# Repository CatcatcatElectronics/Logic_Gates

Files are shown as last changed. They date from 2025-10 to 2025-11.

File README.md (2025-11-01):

# Logic_Gates
A game, a simulator, a gift - the development of logical thinking. The Logic Gate project is designed to develop logical thinking in children and can also be used as a kit - a board for learning C programming and working with microcontrollers from Microchip Corporation.

**_Printed circuit board design_**

## Task:

> Build a simple PCB tutorial project, control LEDs with built-in drivers, explore capacitive sensors for user interface, and learn how to work with a UART serial interface (for DIY projects).

## System Parameters:
> **MCU** - PIC18F27Q84-I/SS,
> **LED_CHIP** - SK6812MINI-EA,
> **USB-BRIDGE** - CH343P,
> **Connecting to a PC** - TYPE-C.

## Functional Diagram project
---

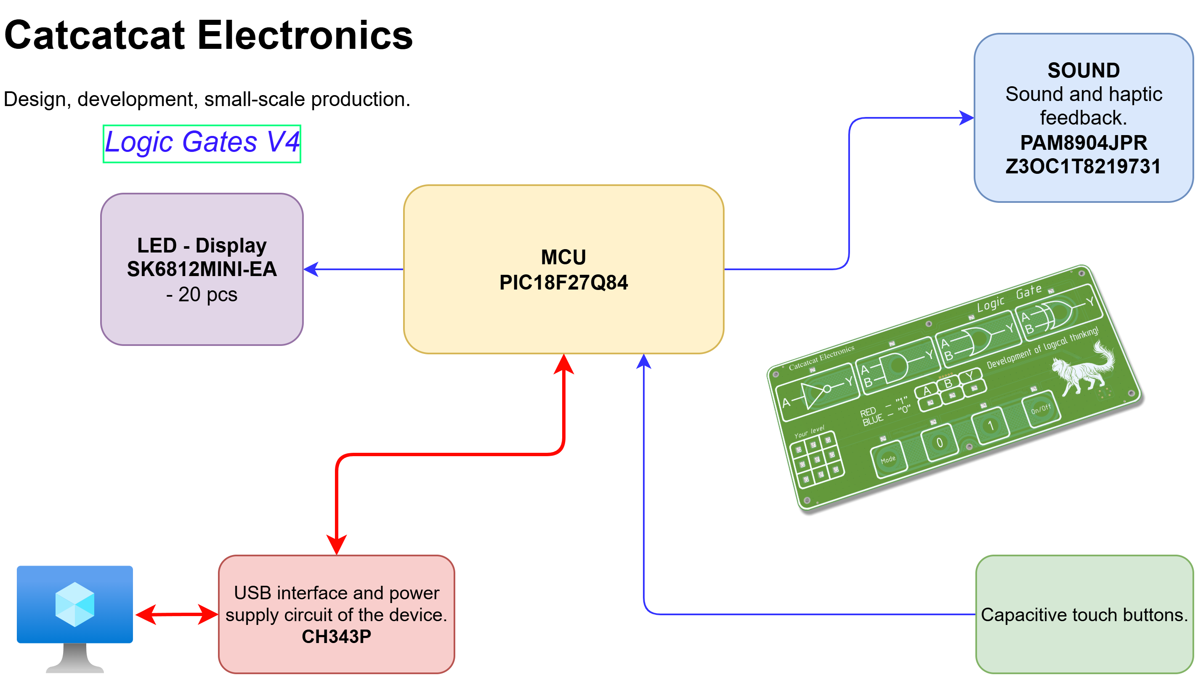
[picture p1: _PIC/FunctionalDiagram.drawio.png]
Functional Diagram of image Functional Diagram


---

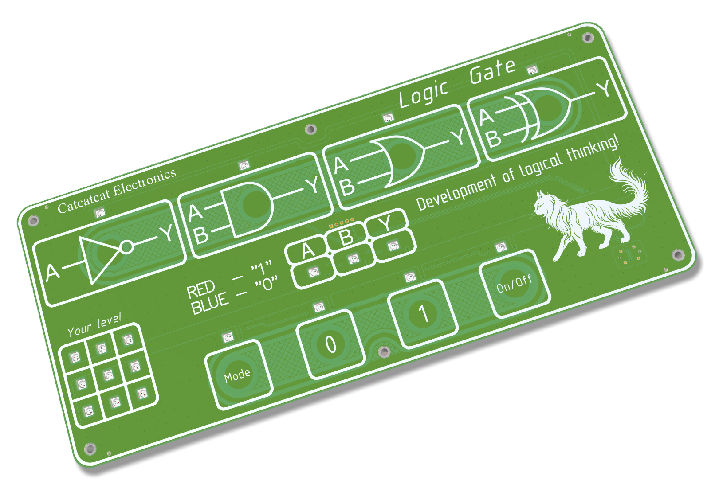
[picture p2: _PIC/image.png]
Semantic description of image Task


## Schematic

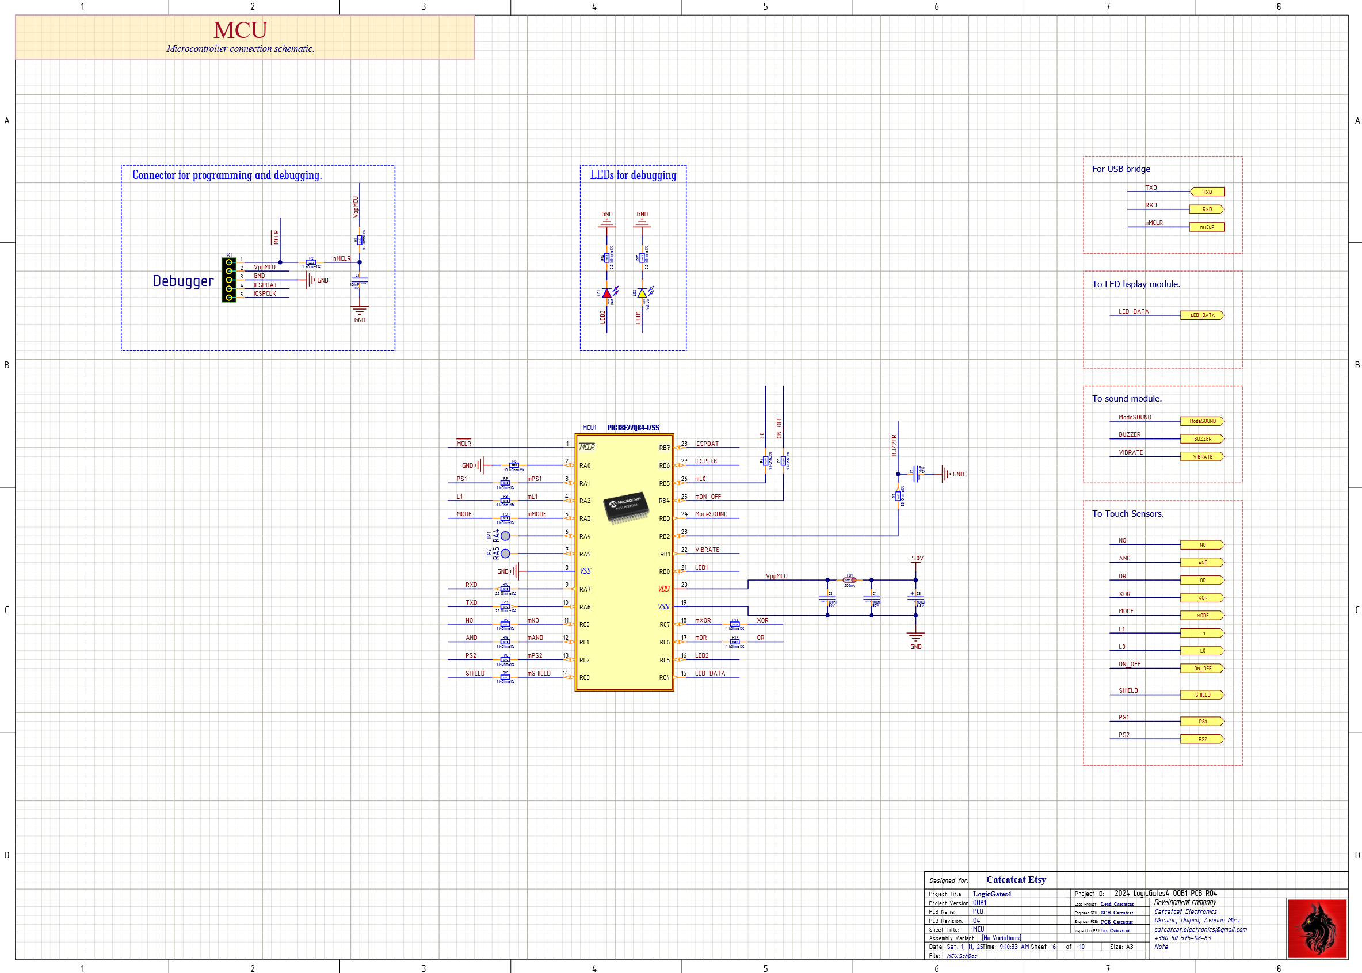
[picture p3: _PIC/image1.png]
Semantic description of image MCU


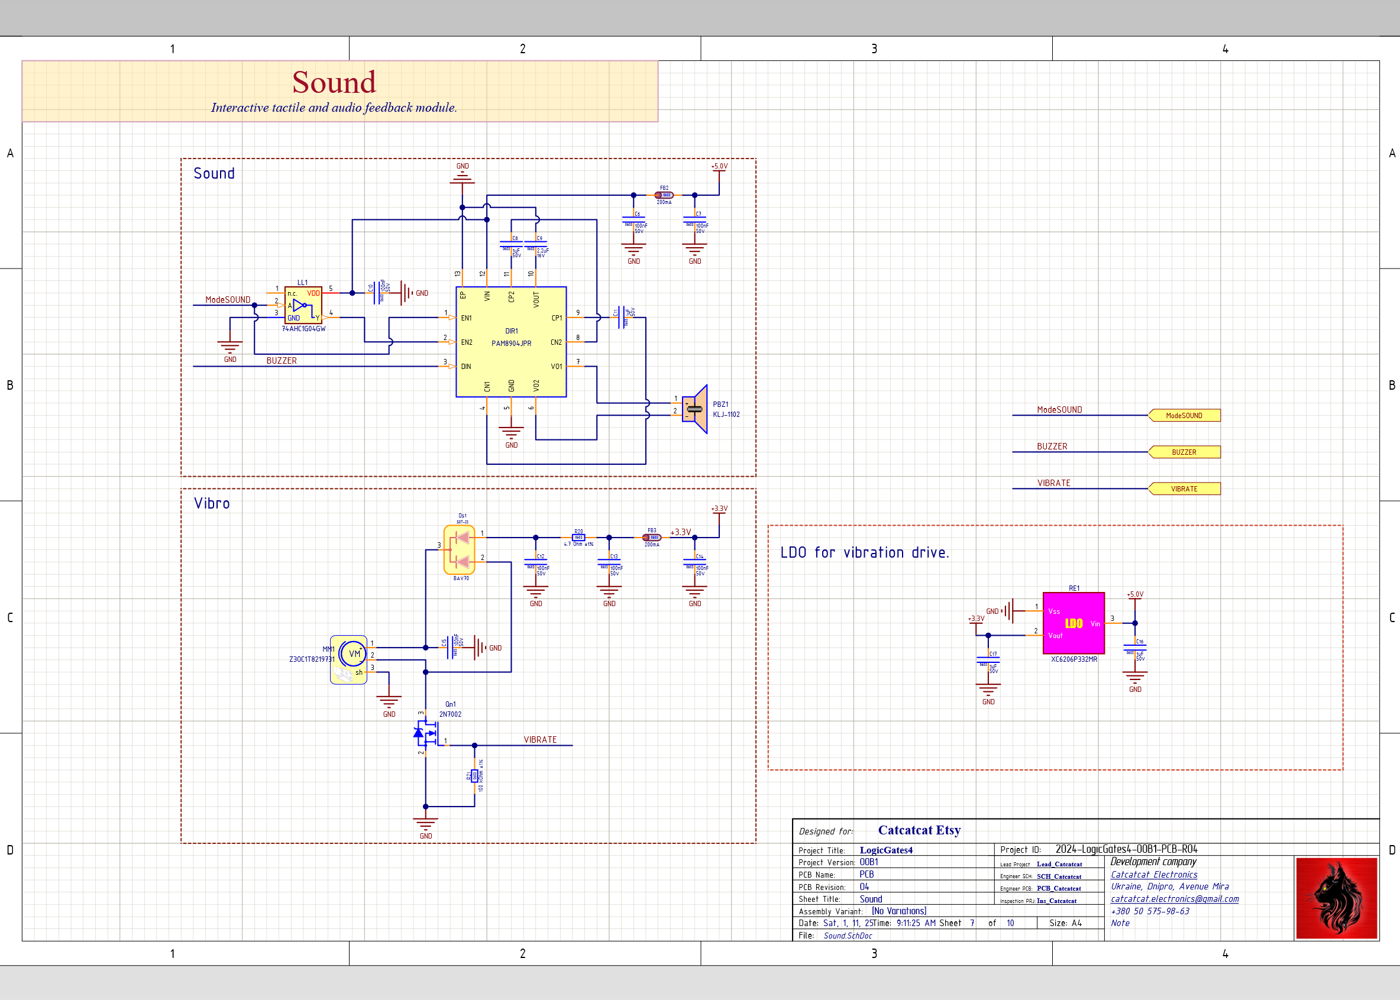
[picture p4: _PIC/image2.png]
Semantic description of image SOUND


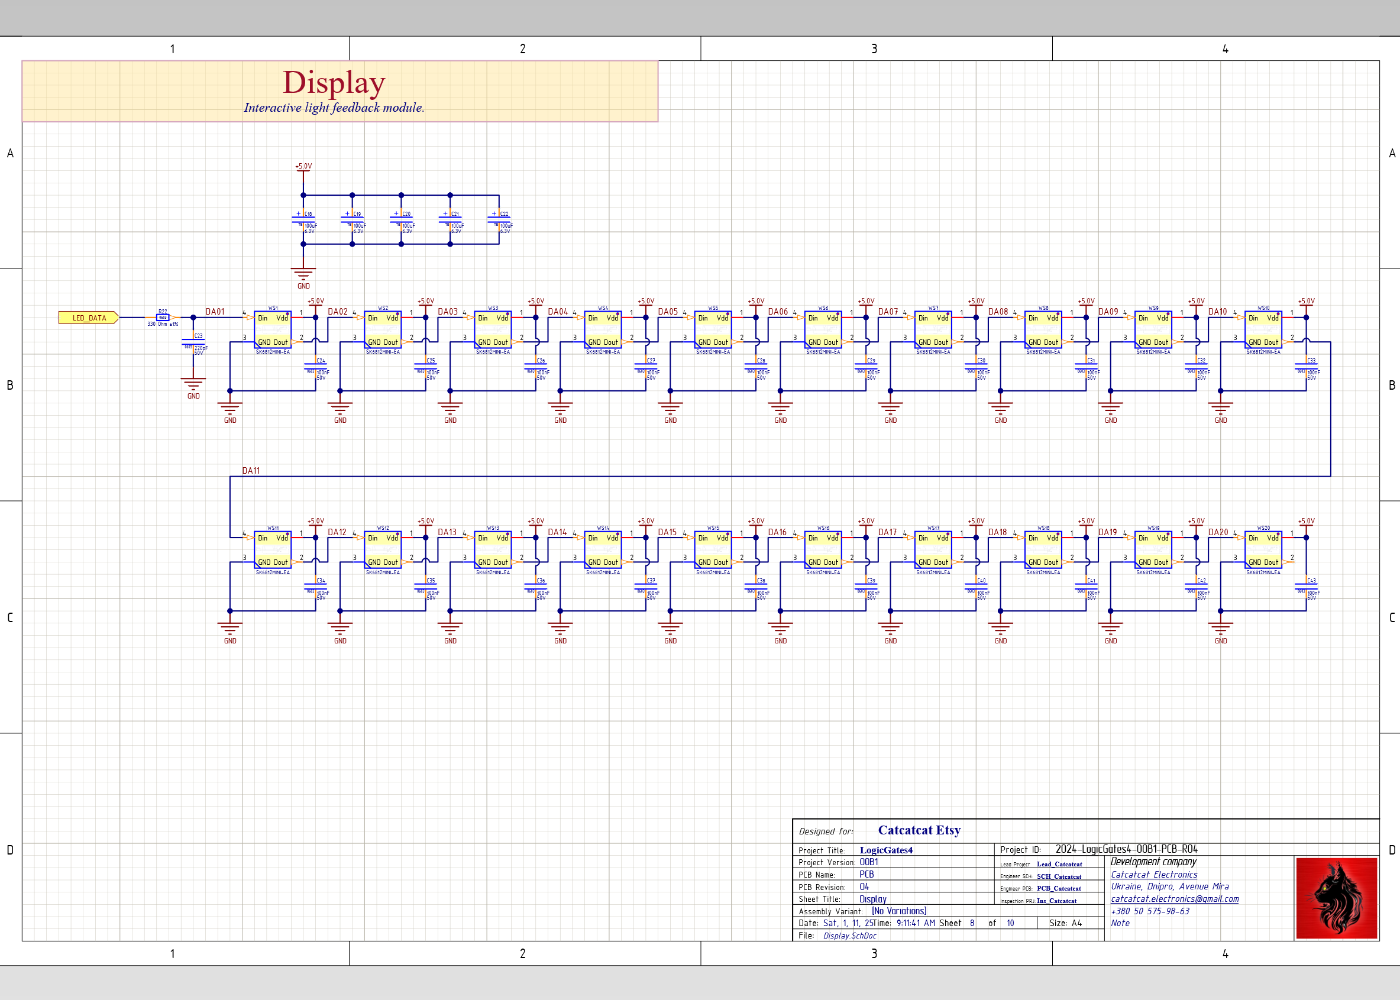
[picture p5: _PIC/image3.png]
Semantic description of image LED-DISPLAY


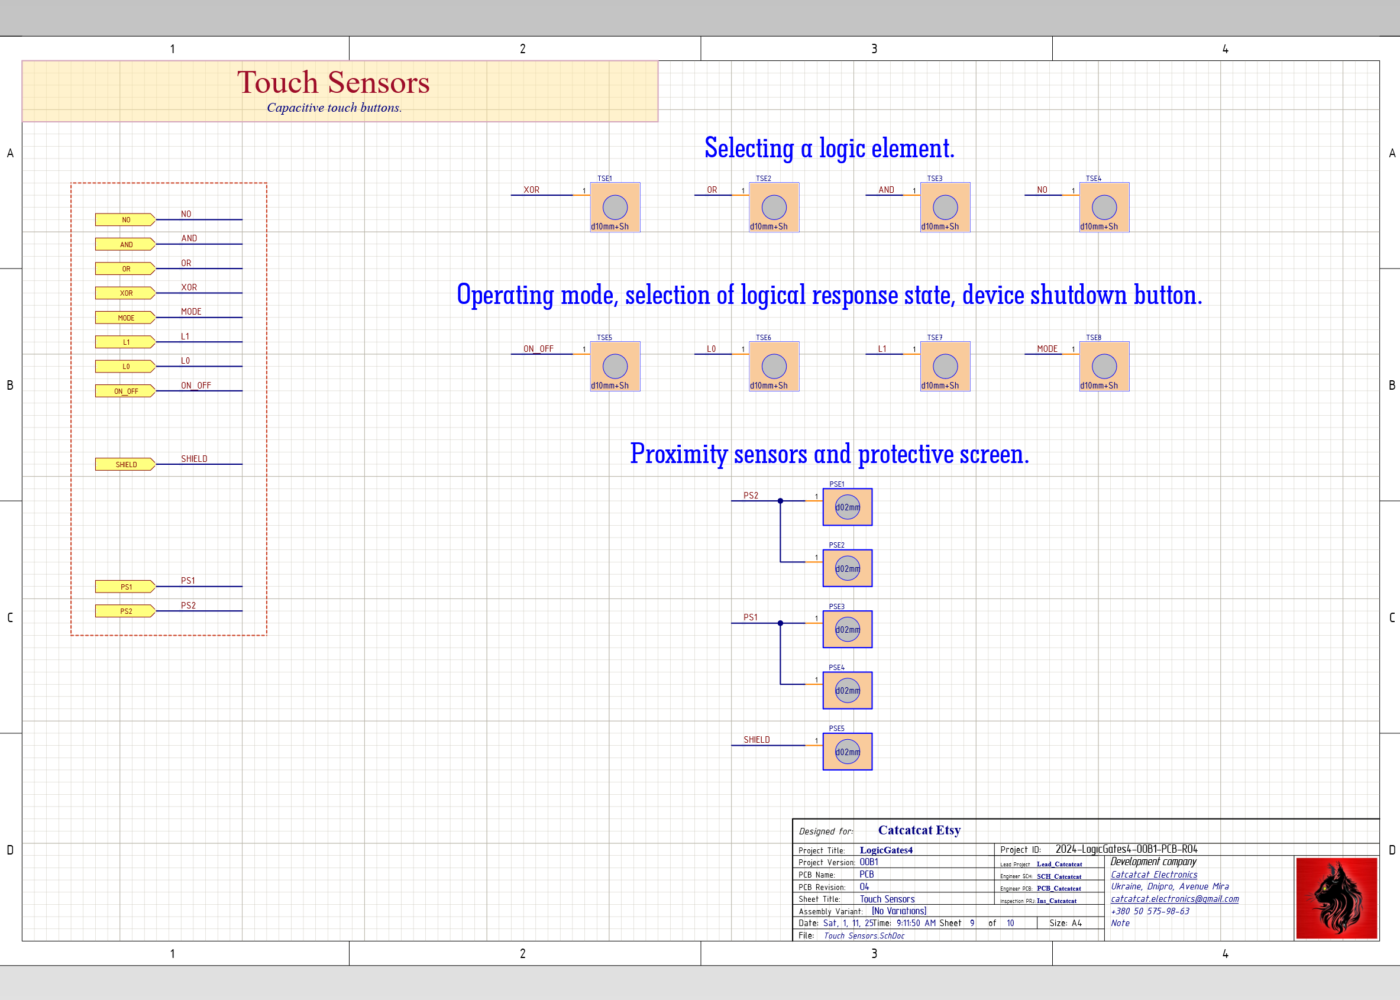
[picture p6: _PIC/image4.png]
Semantic description of image TOUCH


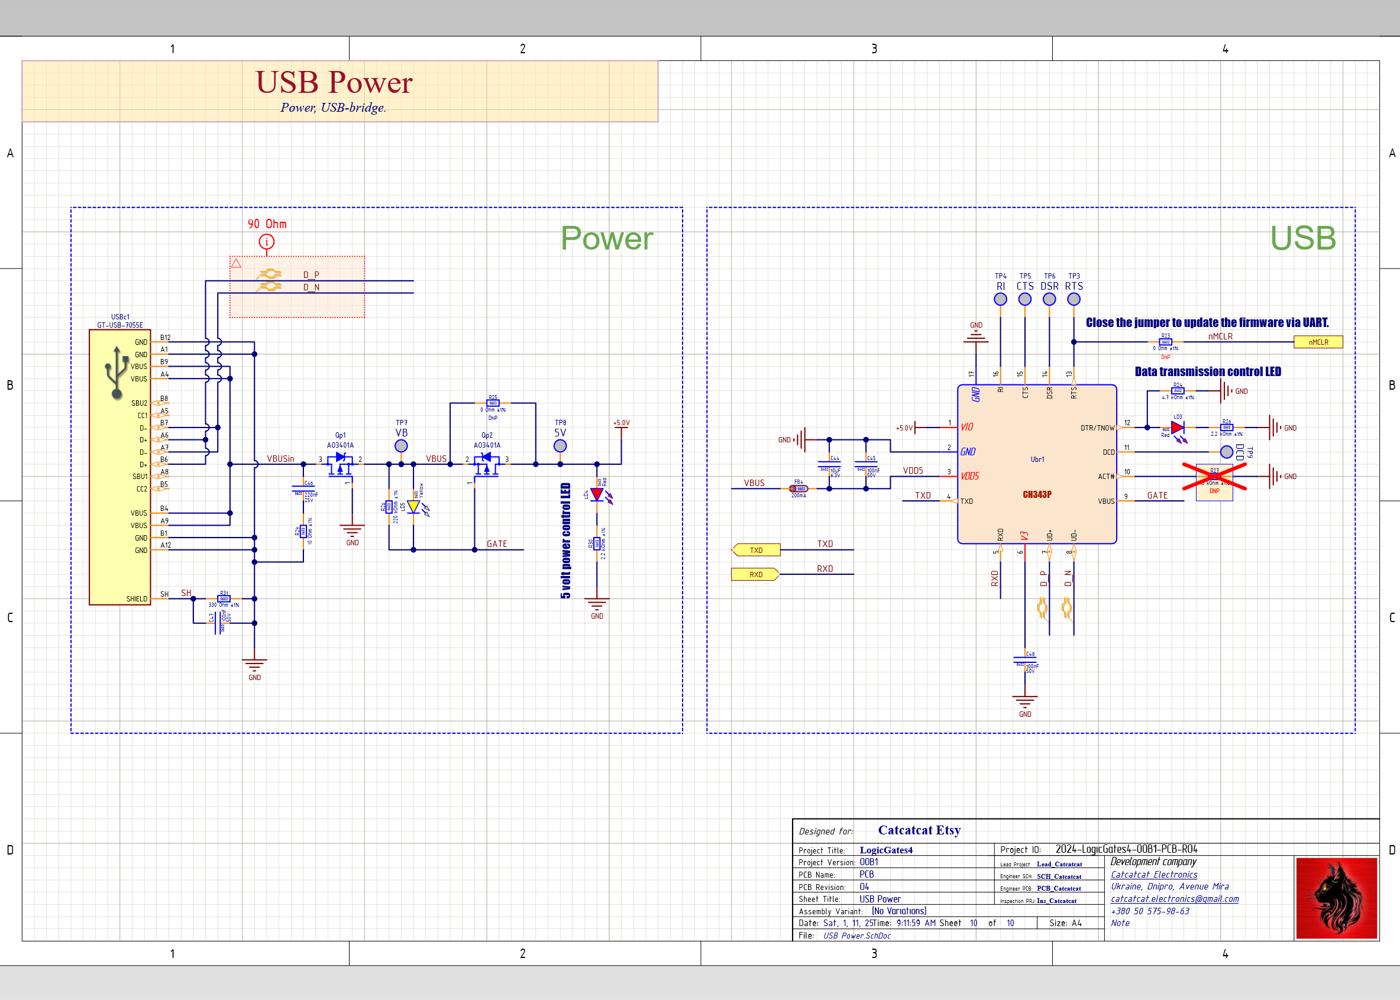
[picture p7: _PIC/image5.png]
Semantic description of image USB-POWER


[**_Schematic_**](https://github.com/CatcatcatElectronics/Logic_Gates/blob/main/Logic_Gates_4/Project%20Outputs/Production%20Files%20JLCPCB/Schematic/2024-LogicGates4-00B1-PCB-R04-Sch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 "View")

[**_Open catalog_**](https://github.com/CatcatcatElectronics/Logic_Gates/tree/main/Logic_Gates_4/Project%20Outputs/Production%20Files%20JLCPCB/Schematic "Open")

---

## 3D Models (STEP & Parasolid)

[**_Open catalog_**](https://github.com/CatcatcatElectronics/Logic_Gates/blob/main/Logic_Gates_4/Project%20Outputs/Production%20Files/3D%20model%20PCB/PCB.rar "Open")

---

## Draftsman
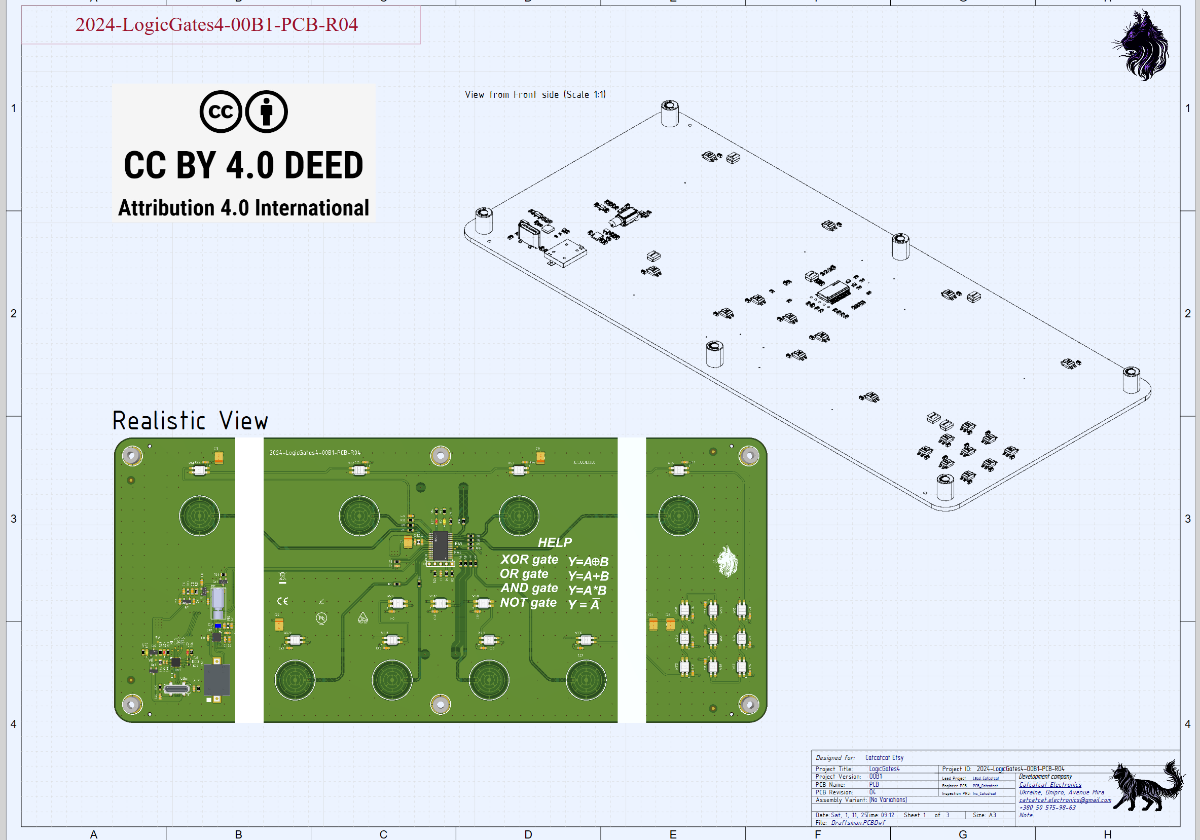
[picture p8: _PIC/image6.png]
Semantic description of image VIEV


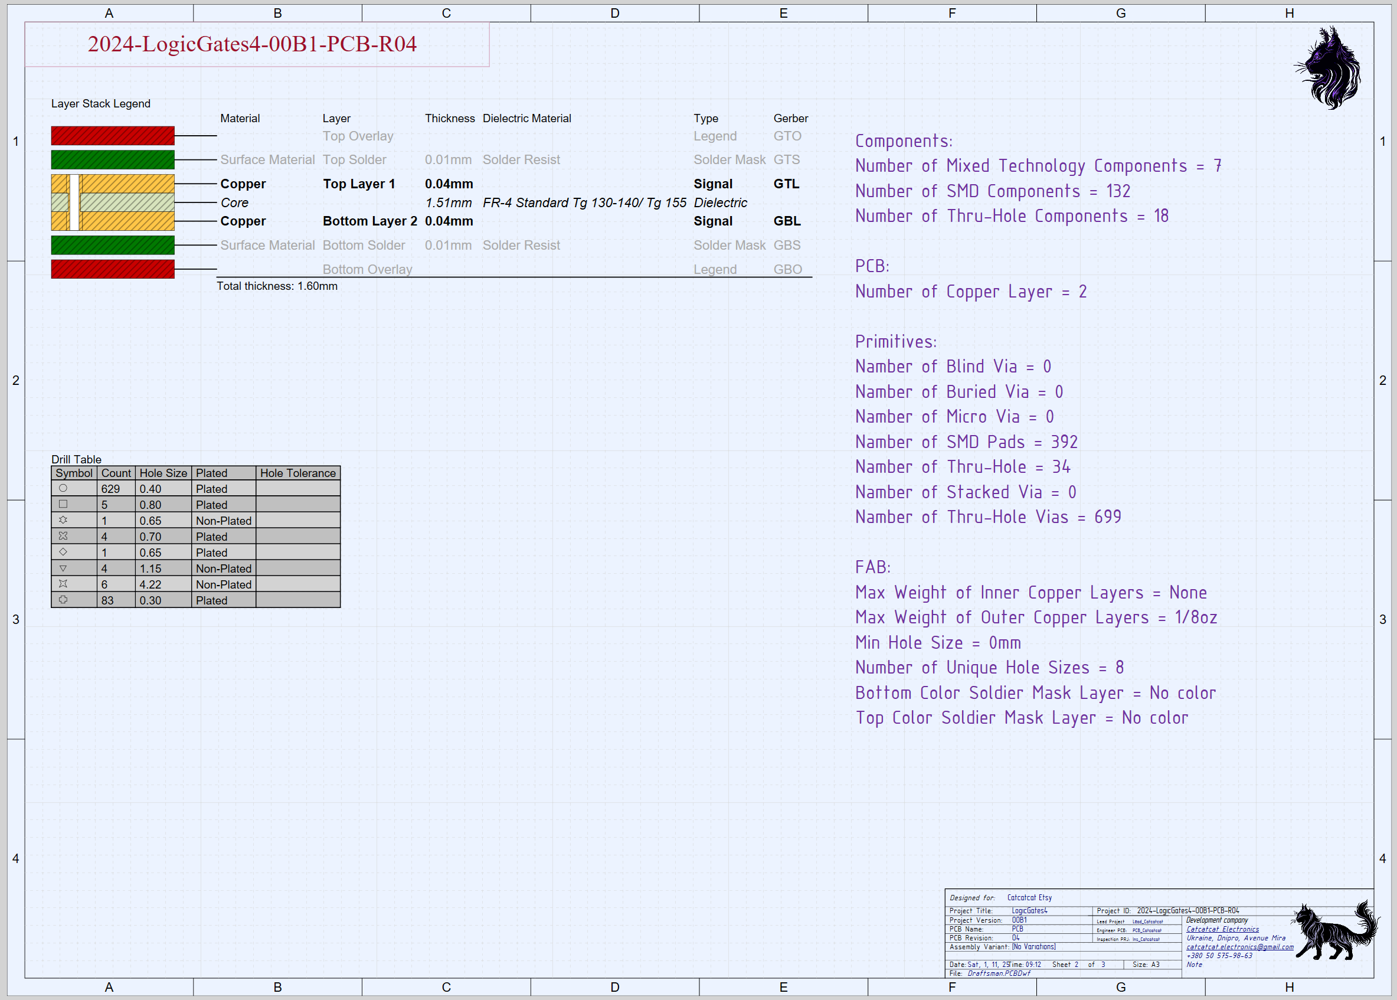
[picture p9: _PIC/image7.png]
Semantic description of image PCB


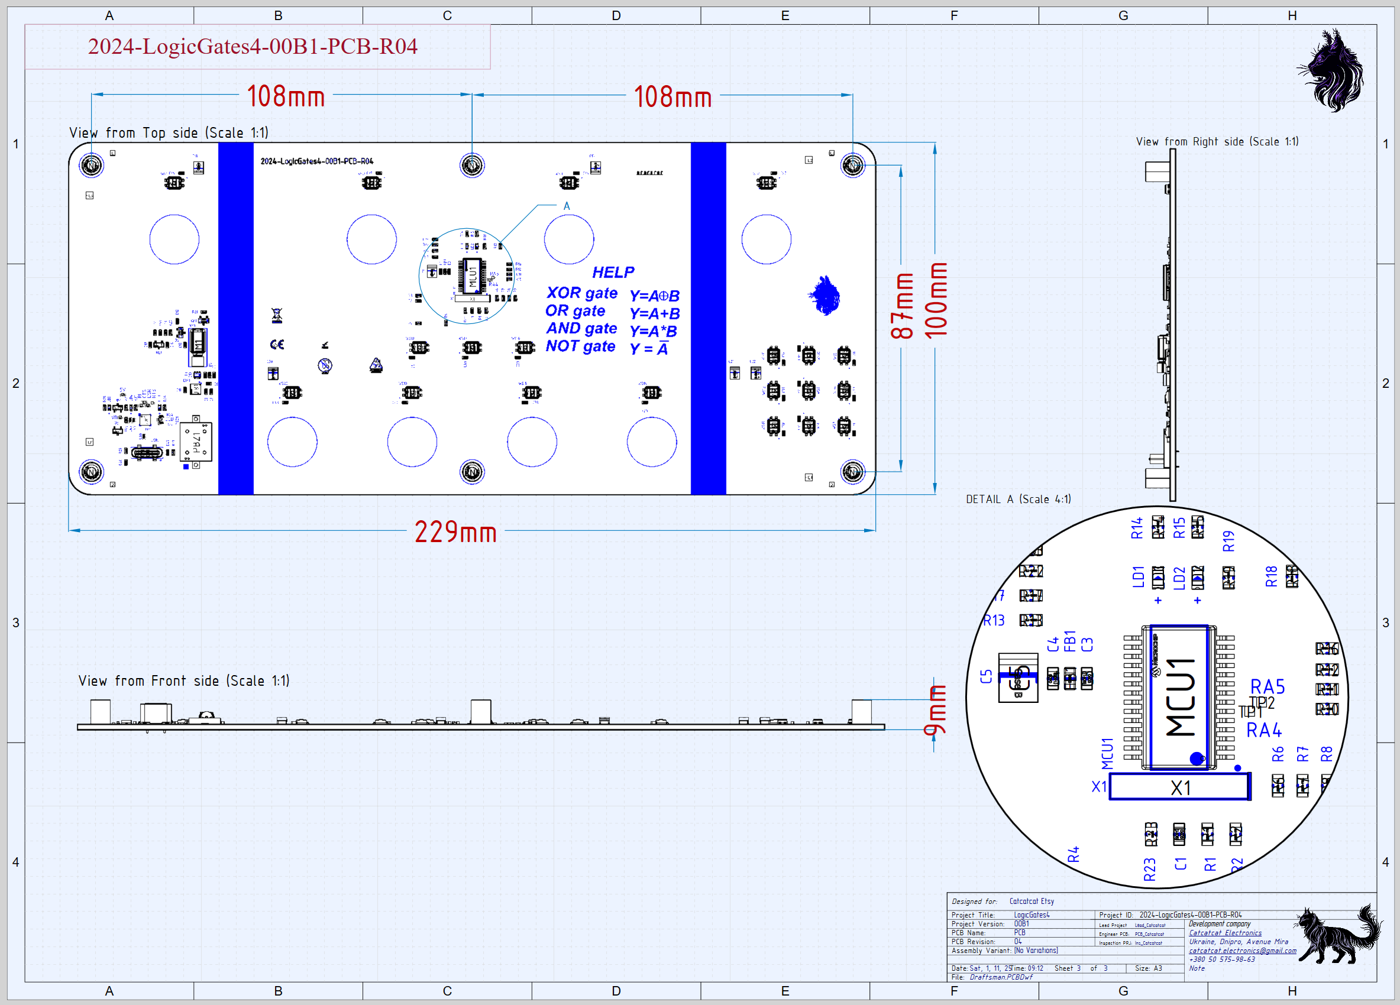
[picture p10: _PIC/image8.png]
Semantic description of image PCB


[**_Draftsman_**](https://github.com/CatcatcatElectronics/Logic_Gates/blob/main/Logic_Gates_4/Project%20Outputs/Production%20Files%20JLCPCB/Draftsman/2024-LogicGates4-00B1-PCB-R01-Dra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 "Viev")

---

## BOM for purchasing components

[**_BOM_**](https://github.com/CatcatcatElectronics/Logic_Gates/blob/main/Logic_Gates_4/Project%20Outputs/Production%20Files%20JLCPCB/Manual%20procurement%20of%20components/2024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 "Download")

---

## GERBER files for production

[**_Open catalog_**](https://github.com/CatcatcatElectronics/Logic_Gates/tree/main/Logic_Gates_4/Project%20Outputs/Production%20Files%20JLCPCB/2024-LogicGates4-00B1-PCB-R01 "Open")

[**_GERBER_**](https://github.com/CatcatcatElectronics/Logic_Gates/blob/main/Logic_Gates_4/Project%20Outputs/Production%20Files%20JLCPCB/2024-LogicGates4-00B1-PCB-R01.zip "Download")

---

## Download project

[**_Download project_**](https://github.com/CatcatcatElectronics/Logic_Gates/blob/main/Logic_Gates_4/Project%20Outputs/Project%20Files/Logic_Gates_4.rar "Download")

---

## Download Firmware

[**_Download Firmware_**](https://github.com/CatcatcatElectronics/Logic_Gates/blob/main/Firmware/Logic_Gates_PIC18F27Q84.X.production.rar "Download")

---

## Image of assembled PCB

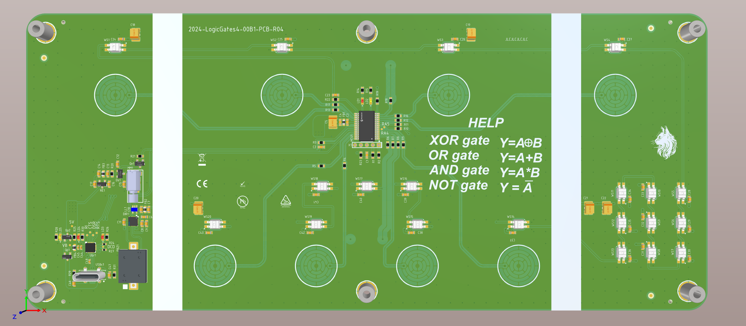
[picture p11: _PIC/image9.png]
Image of assembled PCB Bottom view

-----
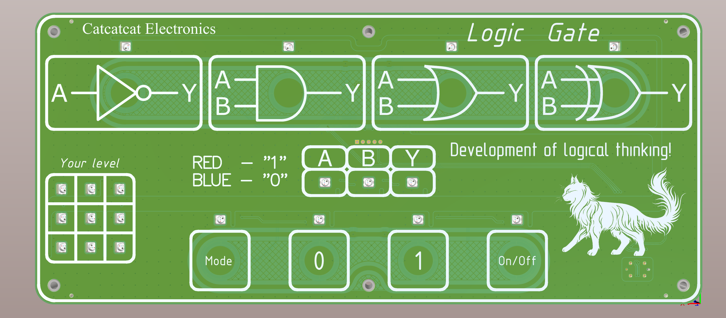
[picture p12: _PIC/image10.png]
Image of assembled PCB Top viev

-----

## *****************************************************************************

## Project status
Release...

Semantic description of image LogicGates

## *****************************************************************************

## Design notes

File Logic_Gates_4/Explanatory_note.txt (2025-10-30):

  1. City:                          Dnipro
     Customer:
     Name of Developer:             Hena Chernov
     Mobile phone:                  +380 (50) 575-98-63

  2. Name of board :                ADMCU-C001-PCB-R01
     Quantity:                      5 pcs.

  3. GERBER-format files :          RS-274-X

  4. Type of board :                4-Layer PCB
     Material Type :                FR4-Standard Tg 130-140
     
     Copper thickness: 
     Outer Copper Weight:           1.0  OZ
     Inner Copper Weight:           0.5  OZ
     
     Min hole size/diameter         0.6/0.3 mm

     PCB Color                      Green
     Silkscreen                     White

  5. Dimensions :                   65.00*35.00 mm
     PCB Thickness :                1.6 mm

  6. Surface Finish :               HASL

  7. Name GERBER-file corresponds to which layer board.

     Top Owerley:                   ADMCU-C001-PCB-R01.GTO
     Top Paste:                     ADMCU-C001-PCB-R01.GTP
     Top Solder Mask:               ADMCU-C001-PCB-R01.GTS
     Top Layer:                     ADMCU-C001-PCB-R01.GTL
     Inner Layer 1:                 ADMCU-C001-PCB-R01.G1
     Inner Layer 2:                 ADMCU-C001-PCB-R01.G2
     Bottom Layer:                  ADMCU-C001-PCB-R01.GBL
     Bottom Solder Mask:            ADMCU-C001-PCB-R01.GBS
     Bottom Paste:                  ADMCU-C001-PCB-R01.GBP
     Bottom Owerley:                ADMCU-C001-PCB-R01.GBO
     Board PCB:                     ADMCU-C001-PCB-R01.GM3
     
     NonPlated holes.(N/C Drill):   ADMCU-C001-PCB-R01-NonPlated.TXT
     Plated holes.(N/C Drill) :     ADMCU-C001-PCB-R01-Plated.TXT

  8. The presence of electrical control (E-Test): yes
  
  9. Notes:     Carry out the contour of the board - only by milling!
                Tolerance of                        +/- 0.15 mm.
                See file for more information       *.EXTREP

  10.   Fabrication Notes for Cavities
        The starting and ending layers for the cavity (L2 and L3 - example)
        The Gerber file containing the cavity routing path    xxxx.GRB
        The routing tool radius     2.00 mm
        The required tolerance on the routing path (usually +/- 0.15 mm)
        The cavity Type as defined in the IPC-6012F standard

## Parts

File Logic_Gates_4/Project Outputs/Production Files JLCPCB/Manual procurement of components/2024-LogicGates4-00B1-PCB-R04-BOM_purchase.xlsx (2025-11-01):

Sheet: BOM Report
Catcatcat Electronics |  | V3.0 (2024/03/05)
Bill of Materials |  |  | BOM Manual assembly for Project [Logic_Gates_4.PrjPcb] (PCB Document : PCB.PcbDoc)
Source Data From: |  | Logic_Gates_4.PrjPcb
Project: |  | Logic_Gates_4.PrjPcb
Variant: |  | None
Creation Date: | Sat, 1, 11, 25 | 10:14
Print Date: | 2025-11-01 | 10:14:54
Production Quantity: | 1
Currency | USD
Case/Package | Comment | LibRef | Designator | Description | Quantity | Supplier 1 | Supplier Part Number 1 | Supplier Unit Price 1 | Sum | Supplier URL | Manufacturer 1 | Manufacturer Part Number 1 | Assembly type
0603 | 100 nF ±10% 50V | 0603 0.1 uF (B) | C1, C3, C4, C6, C7, C10, C12, C13, C14, C15, C24, C25, C26, C27, C28, C29, C30, C31, C32, C33, C34, C35, C36, C37, C38, C39, C40, C41, C42, C43, C47 | 100 nF ±10% 50V X7R | 31 | LCSC | C14663 | 0.0021 | 0.0651 | Click here to go. | YAGEO | CC0603KRX7R9BB104 | Basic Part
0603 | 10 nF ±10% 50V | 0603 0.01 uF (B) | C2 | 10 nF ±10% 50V X7R | 1 | LCSC | C57112 | 0.0012 | 0.0012 | Click here to go. | Guangdong Fenghua Advanced Tech | 0603B103K500NT | Basic Part
CASE-B_3528 | 100UF 6.3V CASE-B_3528 | TANTAL-B 100uF 6.3V (B) | C5, C18, C19, C20, C21, C22 | Tantalum Capacitors 100uF 6.3V CASE-B_3528 RoHS | 6 | LCSC | C16133 | 0.1177 | 0.7062 | Click here to go. | AVX | TAJB107K006RNJ | Basic Part
0603 | 1uF ±10% 50V 0603 | 0603 1.0 uF 50V (B) | C8, C11, C16, C17 | 1.0 uF ±10% 50V X5R | 4 | LCSC | C15849 | 0.0051 | 0.0204 | Click here to go. | Samsung Electro-Mechanics | CL10A105KB8NNNC | Basic Part
0603 | 2.2uF ±10% 16V 0603 | 0603 2.2 uF 16V (B) | C9 | 2.2 uF ±10% 16V X5R | 1 | LCSC | C23630 | 0.0059 | 0.0059 | Click here to go. | Samsung Electro-Mechanics | CL10A225KO8NNNC | Basic Part
0603 | 220 pF ±10% | 0603 0.000220 uF (B) | C23 | 220 pF ±10% 50V X7R | 1 | LCSC | C1603 | 0.0074 | 0.0074 | Click here to go. | Samsung Electro-Mechanics | CL10B221KB8NNNC | Basic Part
0402 | 10 uF 6.3V ±10% | 0402 10 uF 6.3V (B) | C44 | 10 uF ±10% 6.3V X7R | 1 | LCSC | C15525 | 0.0052 | 0.0052 | Click here to go. | Samsung Electro-Mechanics | CL05A106MQ5NUNC | Basic Part
0402 | 100nF 50V ±10% 0402 | 0402 0.1 uF 50V (B) | C45, C48 | 100 nF ±10% 50V X7R | 2 | LCSC | C307331 | 0.0065 | 0.013 | Click here to go. | Guangdong Fenghua Advanced Tech | CL05B104KB54PNC | Basic Part
0603 | 0.22 uF ±10% | 0603 0.22 uF 25V (B) | C46 | 220 nF ±10% 25V X7R | 1 | LCSC | C21120 | 0.0045 | 0.0045 | Click here to go. | Samsung Electro-Mechanics | CL10B224KA8NNNC | Basic Part
UQFN3030-12 | PAM8904JPR | PAM8904JPR (E) | DIR1 | PIEZO SOUNDER DRIVER 18VPP OUTPUT | 1 | LCSC | C780875 | 0.4560 | 0.456 | Click here to go. | Diodes Incorporated | PAM8904JPR | Extended Part
SOT-23 | BAV70 | BAV70 (B) | Ds1 | Switching SOT-23, 200 mA 70 V | 1 | LCSC | C68978 | 0.0195 | 0.0195 | Click here to go. | Changjiang Electronics Tech (CJ) | BAV70 | Basic Part
0603 | GZ1608D601TF | 0603 GZ1608D601TF (B) | FB1, FB2, FB3, FB4 | 0.20A 600 Ohm @100MHz 450 mOhm | 4 | LCSC | C1002 | 0.0045 | 0.018 | Click here to go. | Sunlord | GZ1608D601TF | Basic Part
0603 | KT-0603R | KT-0603R (B) | LD1, LD3, LD4 | 0603 Red 520~625NM 90~100MCD@20MA Top View RoHS | 3 | LCSC | C2286 | 0.0053 | 0.0159 | Click here to go. | Hubei KENTO Elec | KT-0603R | Basic Part
0603 | LED 0603 Yellow 120° 60mW | 19-213/Y2C-CQ2R2L/3T(CY) (B) | LD2, LD5 | 0603 Yellow Colorless transparence -40℃~+85℃ 585.5nm~591.5nm yellow 120° 60mW 0603 Light Emitting Diodes (LED) ROHS | 2 | LCSC | C72038 | 0.0195 | 0.039 | Click here to go. | Everlight Elec | 19-213/Y2C-CQ2R2L/3T(CY) | Basic Part
5-TSSOP, SC-70-5, SOT-353 | 74AHC1G04GW,125 | 74AHC1G04GW,125 (E) | LL1 | IC INVERTER 1CH 1-INP 5TSSOP | 1 | LCSC | C148197 | 0.0493 | 0.0493 | Click here to go. | Nexperia USA Inc. | 74AHC1G04GW,125 | Extended Part
SSOP-28-208mil | PIC18F27Q84-I/SS | PIC18F27Q84-I/SS (E) | MCU1 | SSOP-28, 128KB 1.8V~5.5V PIC 64MHz 25 SSOP-28-208mil Microcontroller Units (MCUs/MPUs/SOCs) ROHS | 1 | LCSC | C2987163 | 3.1065 | 3.1065 | Click here to go. | Microchip Tech | PIC18F27Q84-I/SS | Extended Part
SMD | Z3OC1T8219731 | Z3OC1T8219731 (E) | MM1 | DC Motor Vibration, ROHS | 1 | LCSC | C2894731 | 0.6504 | 0.6504 | Click here to go. | KOTL | Z3OC1T8219731 | Extended Part
SMD,9x11mm | KLJ-1102 | KLJ-1102 (E) | PBZ1 | Piezoelectric buzzer, Externally Driven 70dB@5V,10cm Externally Driven SMD,9x11mm Buzzers ROHS | 1 | LCSC | C201047 | 0.4680 | 0.468 | Click here to go. | KELIKING | KLJ-1102 | Extended Part
SOT-23 | 2N7002 | 2N7002 (B) | Qn1 | N-Channel SOT-23 60V 115mA 200mW 7.5Ω@10V,500mA 2.5V@250uA SOT-23(SOT-23-3) MOSFETs ROHS | 1 | LCSC | C8545 | 0.0139 | 0.0139 | Click here to go. | Changjiang Electronics Tech (CJ) | 2N7002 | Basic Part
SOT-23-3L | AO3401A | AO3401A (B) | Qp1, Qp2 | P-Channel SOT-23-3L 30V 4A 44mΩ@10V,4.3A 1.4W 1.3V@250uAl SOT-23-3L MOSFETs ROHS | 2 | LCSC | C15127 | 0.0591 | 0.1182 | Click here to go. | Alpha & Omega Semicon | AO3401A | Basic Part
0603 | 10K ±1% 0603 | 0603 10 kOhm ±1% (B) | R1, R6 | 10 k (103) ±1% 1/10W | 2 | LCSC | C25804 | 0.0008 | 0.0016 | Click here to go. | Uniroyal Elec | 0603WAF1002T5E | Basic Part
0603 | 1K ±1% 0603 | 0603 1 kOhm ±1% (B) | R2, R4, R5, R7, R8, R9, R12, R13, R16, R17, R18, R19 | 1 k (01B) ±1% 1/10W | 12 | LCSC | C21190 | 0.0005 | 0.006 | Click here to go. | Uniroyal Elec | 0603WAF1001T5E | Basic Part
0603 | 33R ±1% 0603 | 0603 33 Ohm ±1% (B) | R3 | 33 R (330) ±1% 1/10W 50V | 1 | LCSC | C23140 | 0.0014 | 0.0014 | Click here to go. | Uniroyal Elec | 0603WAF330JT5E | Basic Part
0603 | 22R ±1% 0603 | 0603 22 Ohm ±1% (B) | R10, R11 | 22 R (220) ±1% 1/10W 50V | 2 | LCSC | C23345 | 0.0009 | 0.0018 | Click here to go. | Uniroyal Elec | 0603WAF220JT5E | Basic Part
0603 | 2.2K ±1% 0603 | 0603 2.2 kOhm ±1% (B) | R14, R15, R26, R30 | 2.2 k (222) ±1% 1/10W 50V | 4 | LCSC | C4190 | 0.0009 | 0.0036 | Click here to go. | Uniroyal Elec | 0603WAF2201T5E | Basic Part
0603 | 4.7R ±1% 0603 | 0603 4.7 Ohm ±1% (B) | R20 | 4.7 R (4R7) ±1% 1/10W 75V | 1 | LCSC | C23164 | 0.0014 | 0.0014 | Click here to go. | UNI-ROYAL(Uniroyal Elec) | 0603WAF470KT5E | Basic Part
0603 | 100K ±1% | 0603 100 kOhm ±1% (B) | R21 | 100 k (104) ±1% 1/10W 50V | 1 | LCSC | C25803 | 0.0009 | 0.0009 | Click here to go. | UNI-ROYAL(Uniroyal Elec) | 0603WAF1003T5E | Basic Part
0603 | 330 R ±1% | 0603 330 Ohm ±1% (B) | R22, R31 | 330 R (331) ±5% 1/10W 50V | 2 | LCSC | C23138 | 0.0019 | 0.0038 | Click here to go. | Uniroyal Elec | 0603WAF3300T5E | Basic Part
0603 | 0R ±1% 0603 | 0603 0 Ohm ±1% (B) | R23, R25 | 0 R (000) ±5% 1/10W 50V | 2 | LCSC | C21189 | 0.0016 | 0.0032 | Click here to go. | Uniroyal Elec | 0603WAF0000T5E | DNP
0402 | 4.7K ±1% 0402 | 0402 4.7 kOhm ±1% (B) | R24 | 4.7 k (4701)±1% 1/16W 50V | 1 | LCSC | C25900 | 0.0005 | 0.0005 | Click here to go. | UNI-ROYAL(Uniroyal Elec) | 0402WGF4701TCE | Basic Part
0402 | 10K ±1% 0402 50V | 0402 10 kOhm ±1% (B) | R27 | 10 k ±1% 1/16W 50V | 1 | LCSC | C25744 | 0.0004 | 0.0004 | Click here to go. | Uniroyal Elec | 0402WGF1002TCE | DNP
0603 | 220 K ±1% | 0603 220 kOhm ±1% (B) | R28 | 220 k (224) ±5% 1/10W 50V | 1 | LCSC | C22961 | 0.0016 | 0.0016 | Click here to go. | Uniroyal Elec | 0603WAF2203T5E | Basic Part
0603 | 10R ±1% 0603 | 0603 10 Ohm ±1% (B) | R29 | 10 R (XIO) ±1% 1/10W 50V ±400ppm/°C | 1 | LCSC | C22859 | 0.0009 | 0.0009 | Click here to go. | Uniroyal Elec | 0603WAF100JT5E | Basic Part
SOT-23-3L | XC6206P332MR | XC6206P332MR (B) | RE1 | LDO 5.0V 3.3V 200mA Fixed 3.3V~3.3V Positive 6V SOT-23-3L Linear Voltage Regulators (LDO) ROHS | 1 | LCSC | C5446 | 0.0992 | 0.0992 | Click here to go. | Torex Semicon | XC6206P332MR | Basic Part
SMD-M2.5x5.56xLxx+1.53 | SMTSO2570CTJ | Round Nut M2.5xL7.0S (E) | RN1, RN2, RN3, RN4, RN5, RN6 | Nuts Tinning Copper, M2.5 Round Nut L7.0mm | 6 | LCSC | C2916328 | 0.0965 | 0.579 | Click here to go. | Sinhoo | SMTSO2570CTJ | Extended Part
TQFN-16-EP(3x3) | CH343P | CH343P (E) | Ubr1 | USB Bridge, USB 2.0 Transceiver 2Mbps TQFN-16-EP(3x3) | 1 | LCSC | C2846043 | 1.1284 | 1.1284 | Click here to go. | WCH(Jiangsu Qin Heng) | CH343P | Extended Part
SMD | GT-USB-7055E | GT-USB-7055E (E) | USBc1 | Type C V USB 2.0 5A 1 Brick nogging 16P Female -40℃~+85℃ Gold High Conductivity Copper Type-C SMD USB Connectors ROHS | 1 | LCSC | C7450622 | 0.2603 | 0.2603 | Click here to go. | G-Switch | GT-USB-7055E | Extended Part
SMD | SK6812MINI-EA | SK6812MINI-EA (E) | WS1, WS2, WS3, WS4, WS5, WS6, WS7, WS8, WS9, WS10, WS11, WS12, WS13, WS14, WS15, WS16, WS17, WS18, WS19, WS20 | TTB 12mA 5.2V -40℃~+80℃ RGB LEDs(Built-in IC) | 20 | LCSC | C5378731 | 0.1573 | 3.146 | Click here to go. | OPSCO Optoelectronics | SK6812MINI-EA | Extended Part
 | PL2N-05n | PL2N-05n | X1 | 2.0 mm | 1 |  |  |  | 0 | Click here to go. | http://www.jinlingdz.com |  | Manual Part
 |  |  |  |  | 127 |  |  | Total cost of components per PCB 1 pcs. | $11.02
Approved |  | Notes

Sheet: Project Information
Project Full Path | D:\Project\Project_Altium\Pr_2026\_GITHAB\Logic_Gates\_6_Project\Logic_Gates_4\Logic_Gates_4.PrjPcb
Project Filename | Logic_Gates_4.PrjPcb
Variant Name | None
Data-Source Filename | Logic_Gates_4.PrjPcb
Data-Source Full Path | D:\Project\Project_Altium\Pr_2026\_GITHAB\Logic_Gates\_6_Project\Logic_Gates_4\Logic_Gates_4.PrjPcb
Title | BOM Manual assembly for Project [Logic_Gates_4.PrjPcb] (PCB Document : PCB.PcbDoc)
Total Quantity | 127
Report Time | 10:14
Report Date | Sat, 1, 11, 25
Report Date & Tine | Sat, 1, 11, 25 10:14
Output Name | BOM Manual assembly
Output Type | BomReport
Output Generator Name | BOM
Output Generator Description | Bill of Materials
Customer | Catcatcat Etsy
Engineer | PCB_Catcatcat

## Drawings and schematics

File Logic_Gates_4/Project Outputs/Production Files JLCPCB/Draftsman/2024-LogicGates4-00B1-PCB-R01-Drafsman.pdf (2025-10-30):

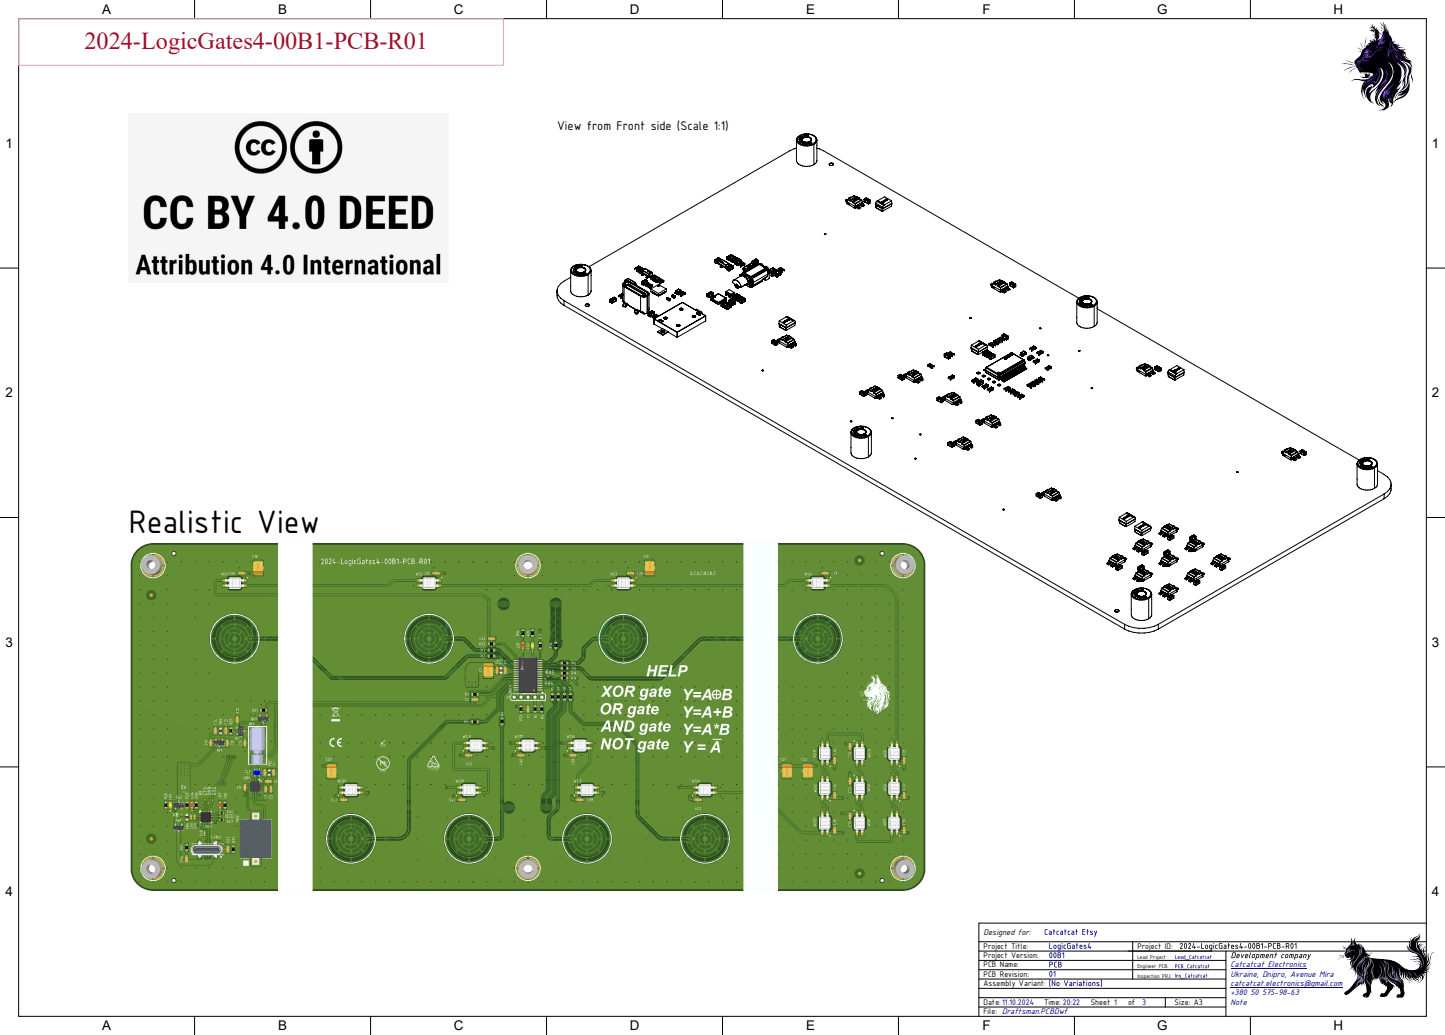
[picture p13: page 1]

View from Front side (Scale 1:1)

PCB Name: | Engineer PCB:
PCB Revision: | Inspection PRJ:

Catcatcat Electronics
Ukraine, Dnipro, Avenue Mira
catcatcat.electronics@gmail.com

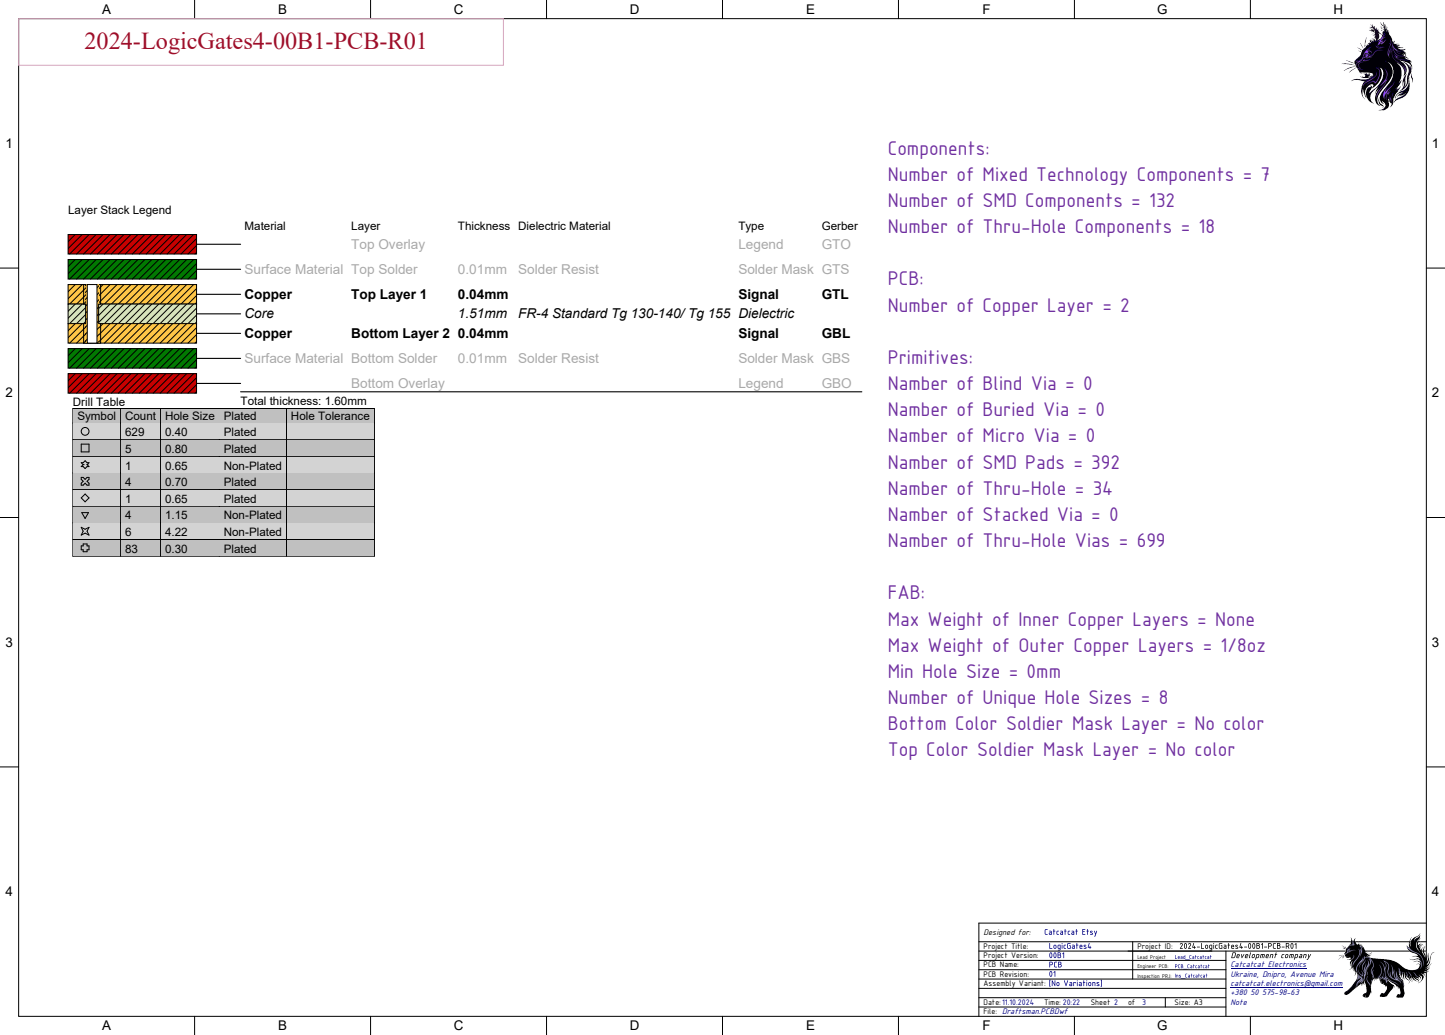
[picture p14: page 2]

Components:
Number of Mixed Technology Components = 7
Number of SMD Components = 132
Number of Thru-Hole Components = 18

PCB:
Number of Copper Layer = 2

Primitives:
Namber of Blind Via = 0
Namber of Buried Via = 0
Namber of Micro Via = 0
Namber of SMD Pads = 392
Namber of Thru-Hole = 34
Namber of Stacked Via = 0
Namber of Thru-Hole Vias = 699

Symbol | Count | Hole Size | Plated | Hole Tolerance

629 | 0.40 | Plated
5 | 0.80 | Plated
1 | 0.65 | Non-Plated
4 | 0.70 | Plated
1 | 0.65 | Plated
4 | 1.15 | Non-Plated
6 | 4.22 | Non-Plated
83 | 0.30 | Plated

FAB:
Max Weight of Inner Copper Layers = None
Max Weight of Outer Copper Layers = 1/8oz
Min Hole Size = 0mm
Number of Unique Hole Sizes = 8
Bottom Color Soldier Mask Layer = No color
Top Color Soldier Mask Layer = No color

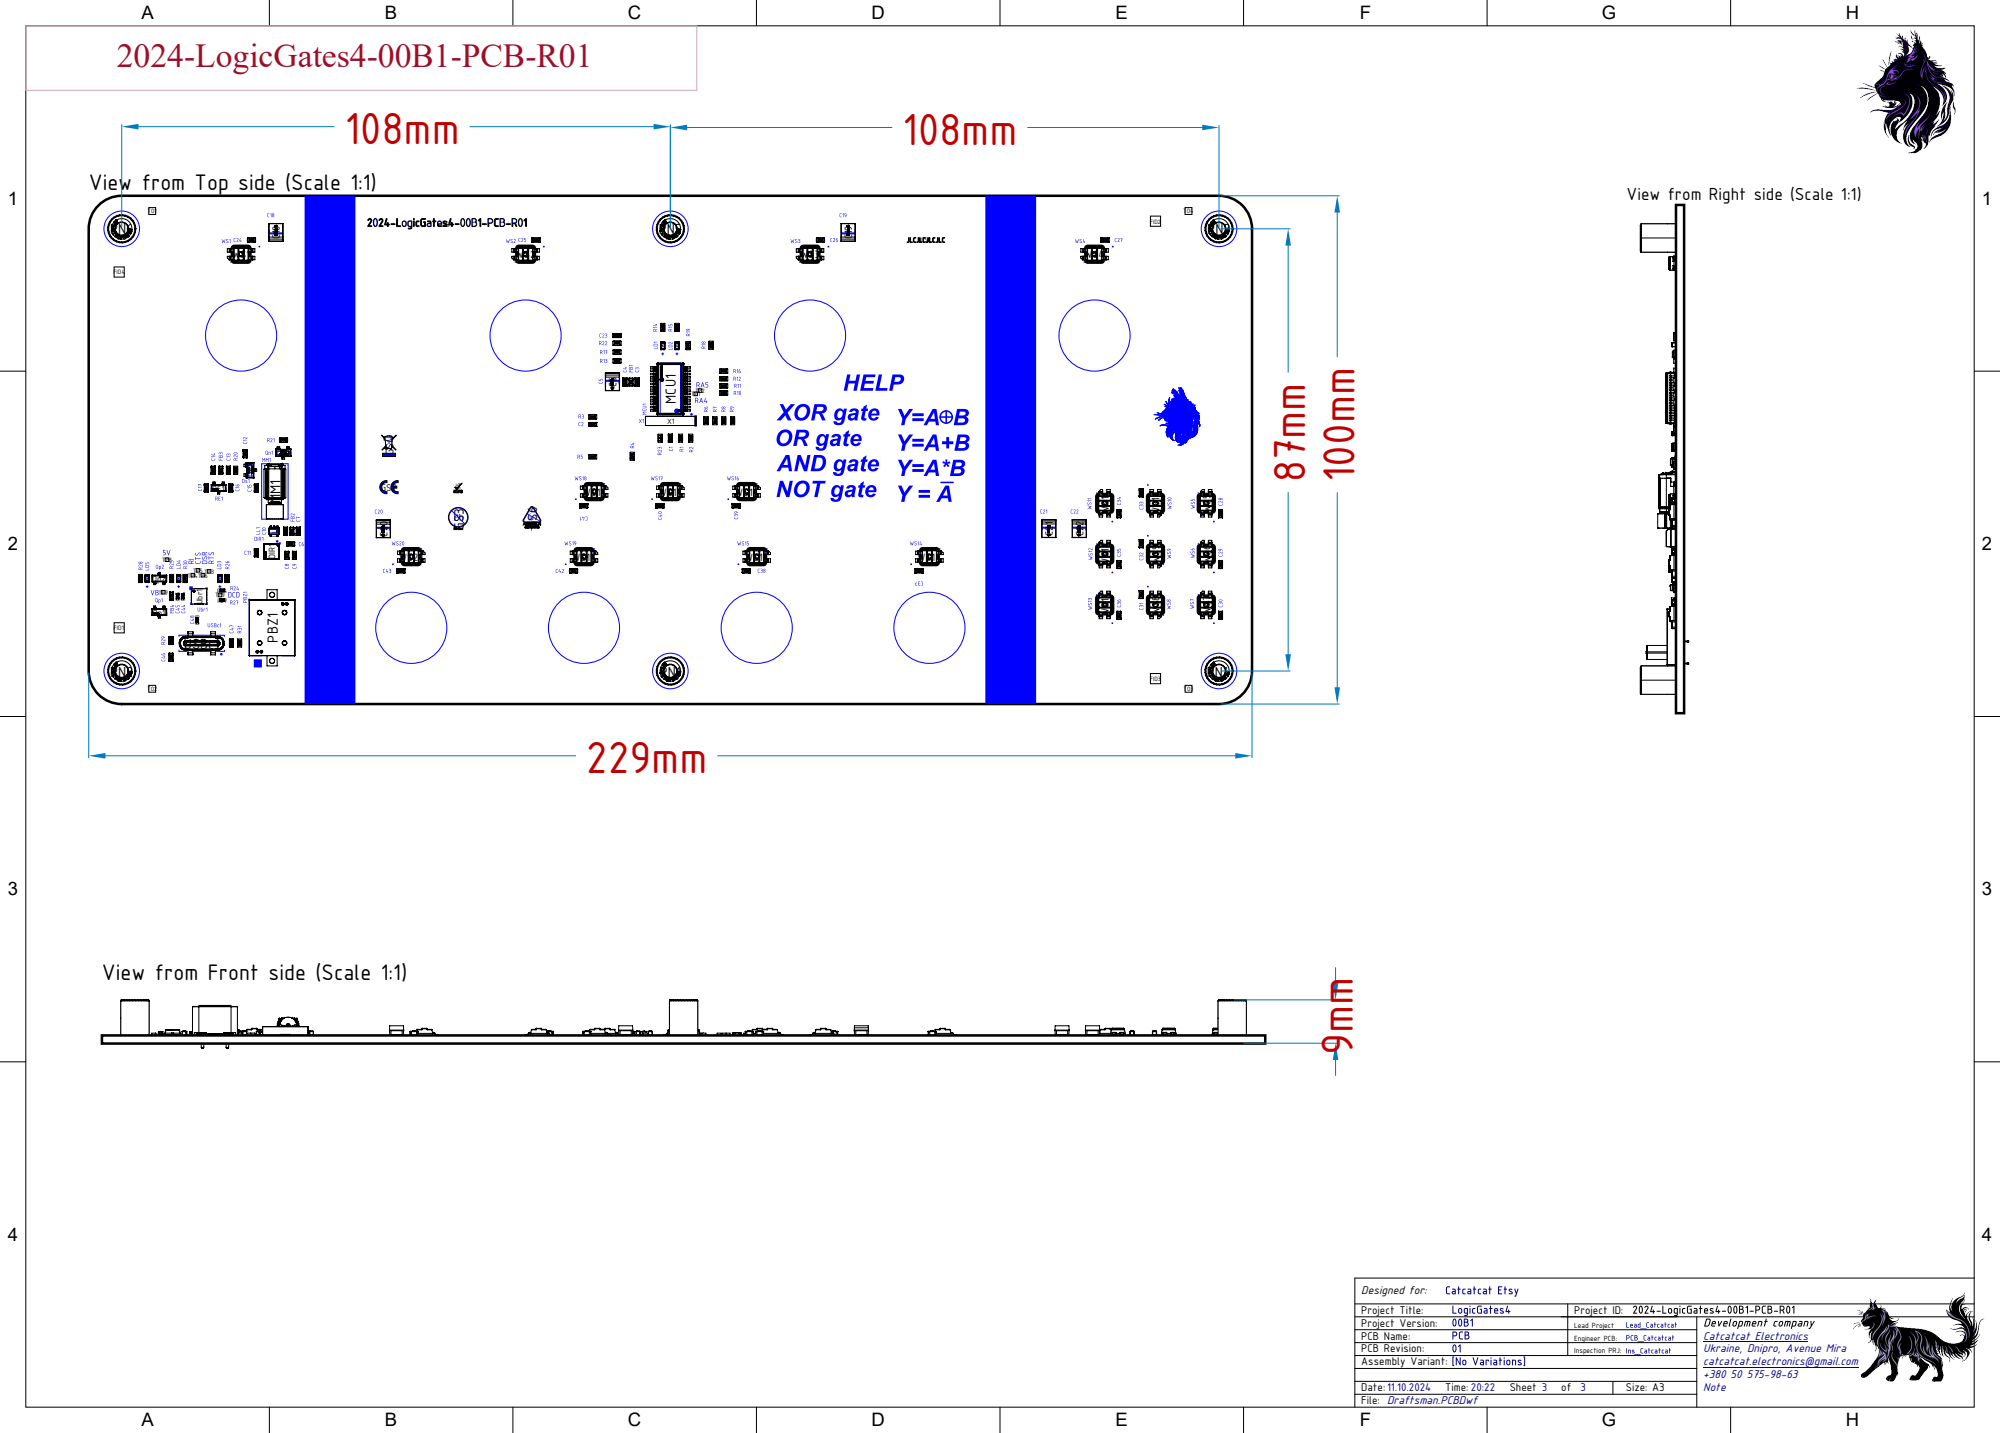
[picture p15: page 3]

View from Top side (Scale 1:1)

View from Right side (Scale 1:1)

View from Front side (Scale 1:1)

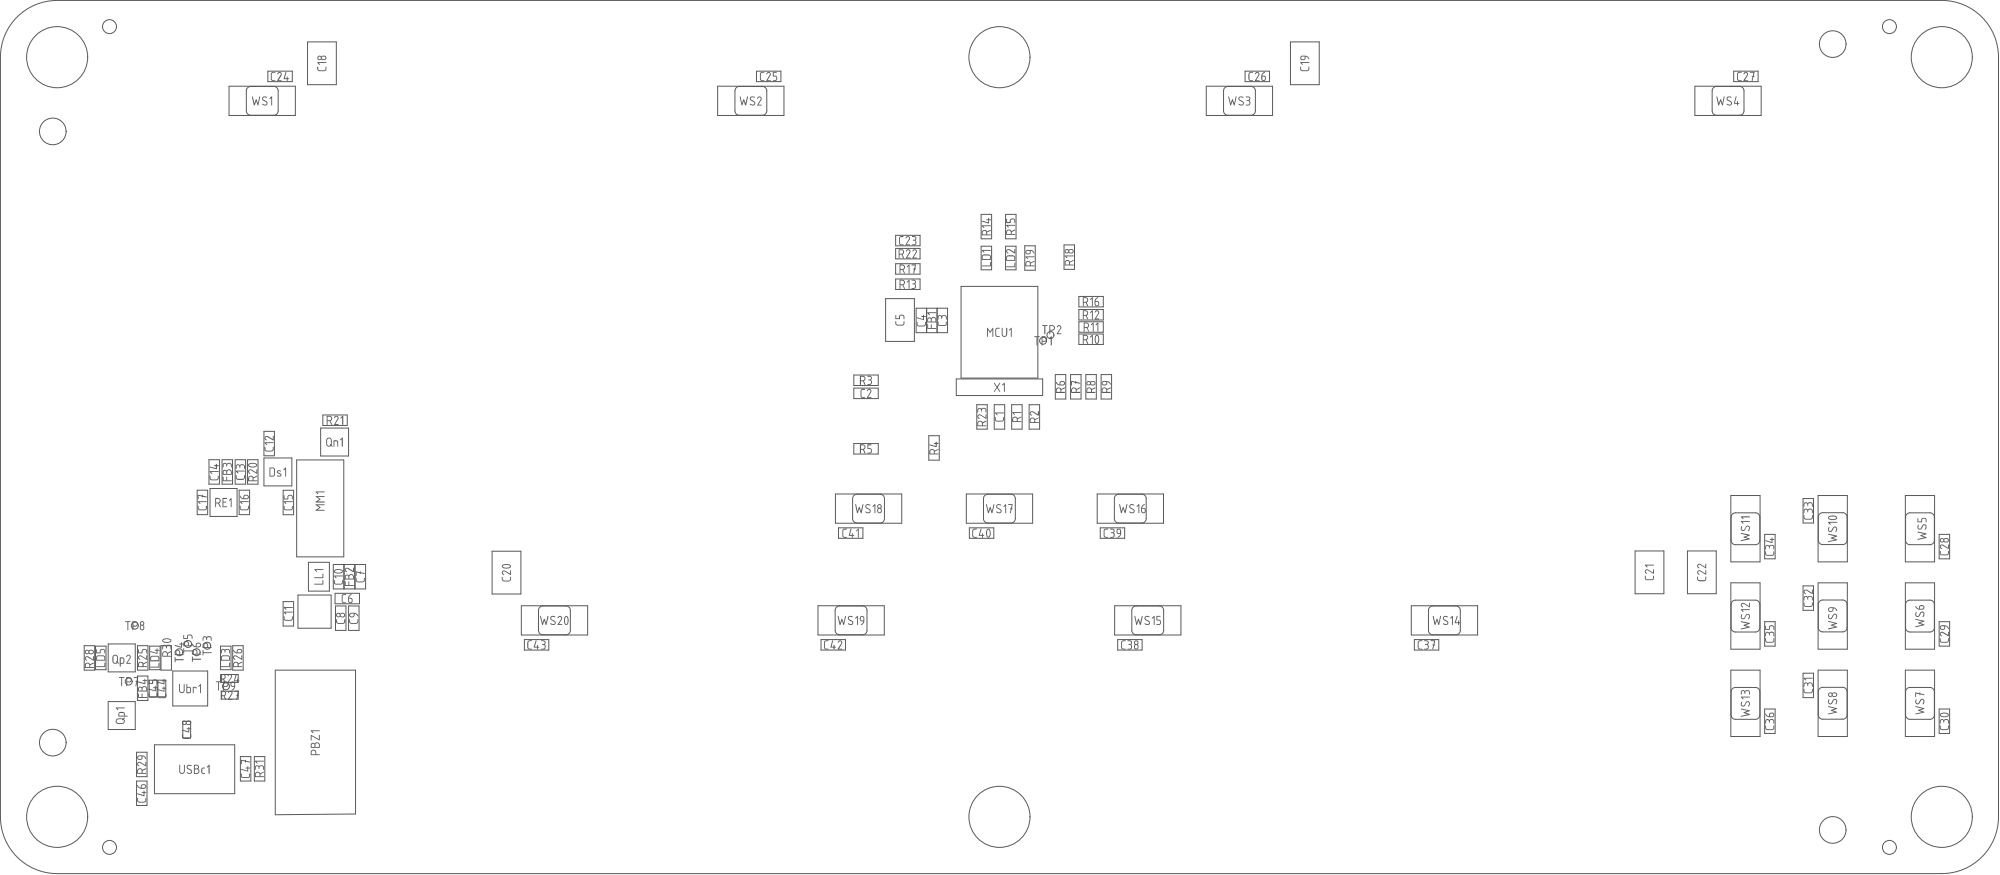
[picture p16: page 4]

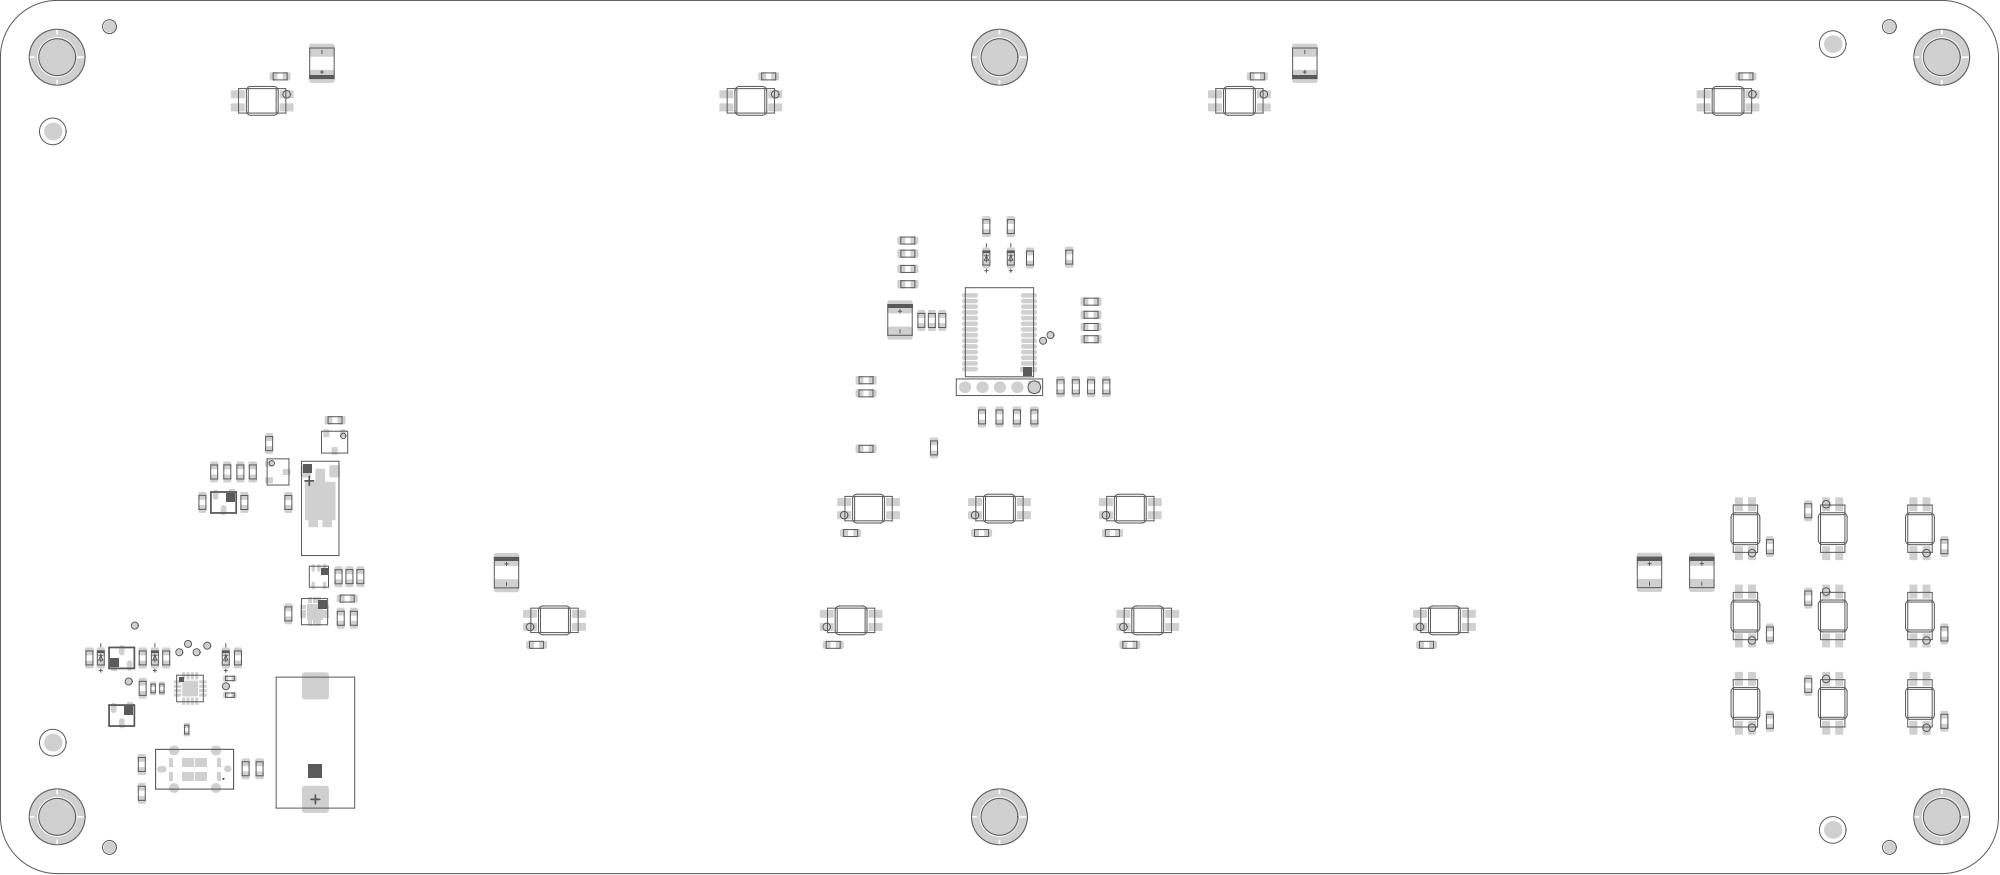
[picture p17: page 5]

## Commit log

2025-10-30 Test Altium's
    [Additional Documents.SchDoc, Functional Diagram.SchDoc]
2025-10-31 test token
    [MCU.SchDoc]
2025-10-31 Last updates
    [Functional Diagram.SchDoc]
2025-10-31 update readmi
    [Assembly.SchDoc]
2025-11-01 ADD PIC
    [MCU.SchDoc, USB Power.SchDoc]
2025-11-01 ADD 3d model
    [MCU.SchDoc]
2025-11-01 ADD BOM
    [2024-LogicGates4-00B1-PCB-R04-BOM_purchase.xlsx]
